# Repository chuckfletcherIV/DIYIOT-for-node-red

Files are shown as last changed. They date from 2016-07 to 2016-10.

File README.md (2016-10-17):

# DIYIOT
Open source IOT hardware and software platform based on cheap commodity sensors, ESP8266-12e chips, the MQTT protocol and powered by IBM's Node-Red (pre-installed with most new raspberry Pi 3 installations).

The goal of the project is to put sensors (and actuators like servos or leds) on a local wifi network as inexpensively as possible, ideally for under $7 or 8 per device (including a power supply). 

Using Node-red, these devices can trigger or be triggered by any IOT activity you can think of. Node-red has dozens of supported IOT hooks to services and devices, like Hue or Lifx light bulbs, twitter integration or even the ability to send txt messages via twilio.

No coding is required for basic functionality. All data is sent to Node-red for processing and triggering. Node-red lets you do alot without coding as well, but if you need to code, you can do what you need to with simple javascript. 

DIYIOT is great for home automation projects, DIY escape rooms and halloween displays, and even interactive installations. For more permanent installations, sensors can be soldered directly into the board, vs using a header (which makes the sensor swappable). 

See DIY Board and Sensor Pin Map to figure out what board to use for which sensor (or actuator), also see notes for more advanced usage.

You can use www.PCBGOGO.com to get your own boards made for under $1 each. Gerber files are available for download from our site under "PCB". Keep an eye out for other sources for DIYIOT boards over the coming months. 

If you find a cheap commodity sensor that works great with an exisiting board - let us know so we can add it to the list.

If there is a problem with a sensor firmware code, or pin map, let us know or share a fix.

Future project goals:

Automatic Device Discovery with mDNS (bonjour)

SSL Level Security 

Smaller board size

Long term power and battery opimization

Even more cost reduction per device if we can find engineering and manufacturing partners to work with. 

Thanks, 

the DIYIOT team

Join the DIYIOT for Node Red mailing list at https://groups.google.com/forum/#!forum/diyiot-node-red

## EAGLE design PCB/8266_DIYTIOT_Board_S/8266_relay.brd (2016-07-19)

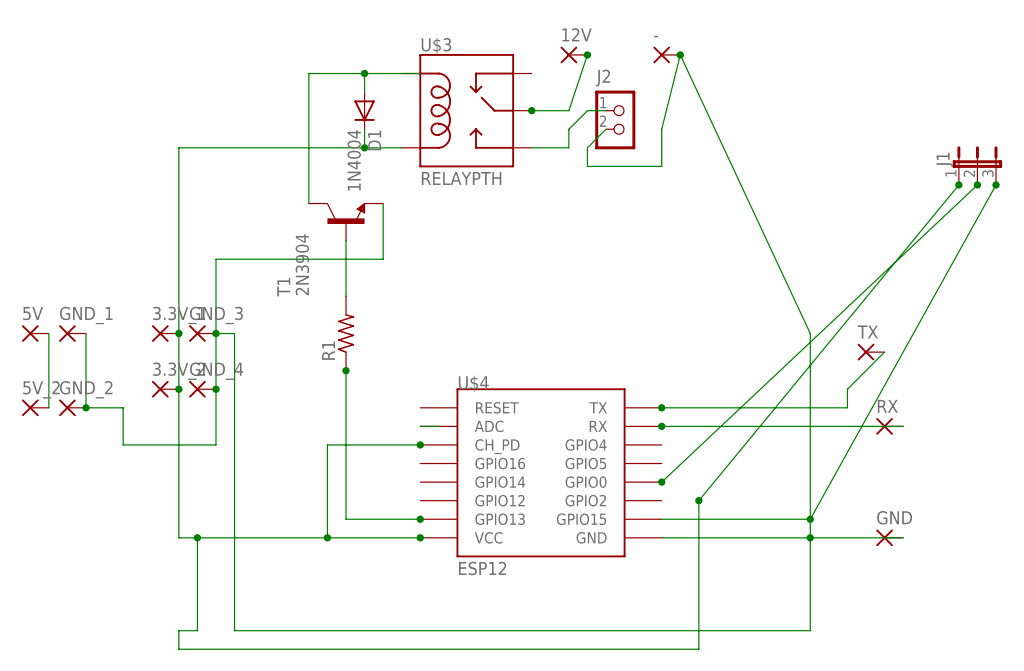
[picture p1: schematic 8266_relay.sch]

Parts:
3.3V_1, 3.3V_2, 5V, 5V_2, 12V: 2,15/1,0
-: 2,15/1,0
D1: 1N4004; DO41-10
GND: 2,15/1,0
GND_1, GND_2, GND_3, GND_4: 2,15/1,0
J1: JP2E; JP2
J2: CON_TERMINAL_BLOCK_02-5MM; TERMINAL_BLOCK_2P_5
R1: R-US_0309/10; 0309/10
RX: 2,15/1,0
T1: 2N3904; TO92
TX: 2,15/1,0
U$3: RELAYPTH; SRD-05VDC-SL-C
U$4: ESP12

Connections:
5V: 5V.1, 5V_2.1
12V: 12V.1, U$3.SWCOMMON
GND: -.1, GND.1, GND_1.1, GND_2.1, GND_3.1, GND_4.1, J1.3, J2.2, T1.3 (E), U$4.GND, U$4.GPIO15
unnamed: J1.2, U$4.GPIO0
unnamed: R1.1, U$4.GPIO13
unnamed: J2.1, U$3.SWOPEN
unnamed: 3.3V_1.1, 3.3V_2.1, D1.C, J1.1, U$3.COIL0, U$4.CH_PD, U$4.VCC
unnamed: D1.A, T1.1 (C), U$3.COIL1
unnamed: R1.2, T1.2 (B)
RX: RX.1, U$4.RX
TX: TX.1, U$4.TX

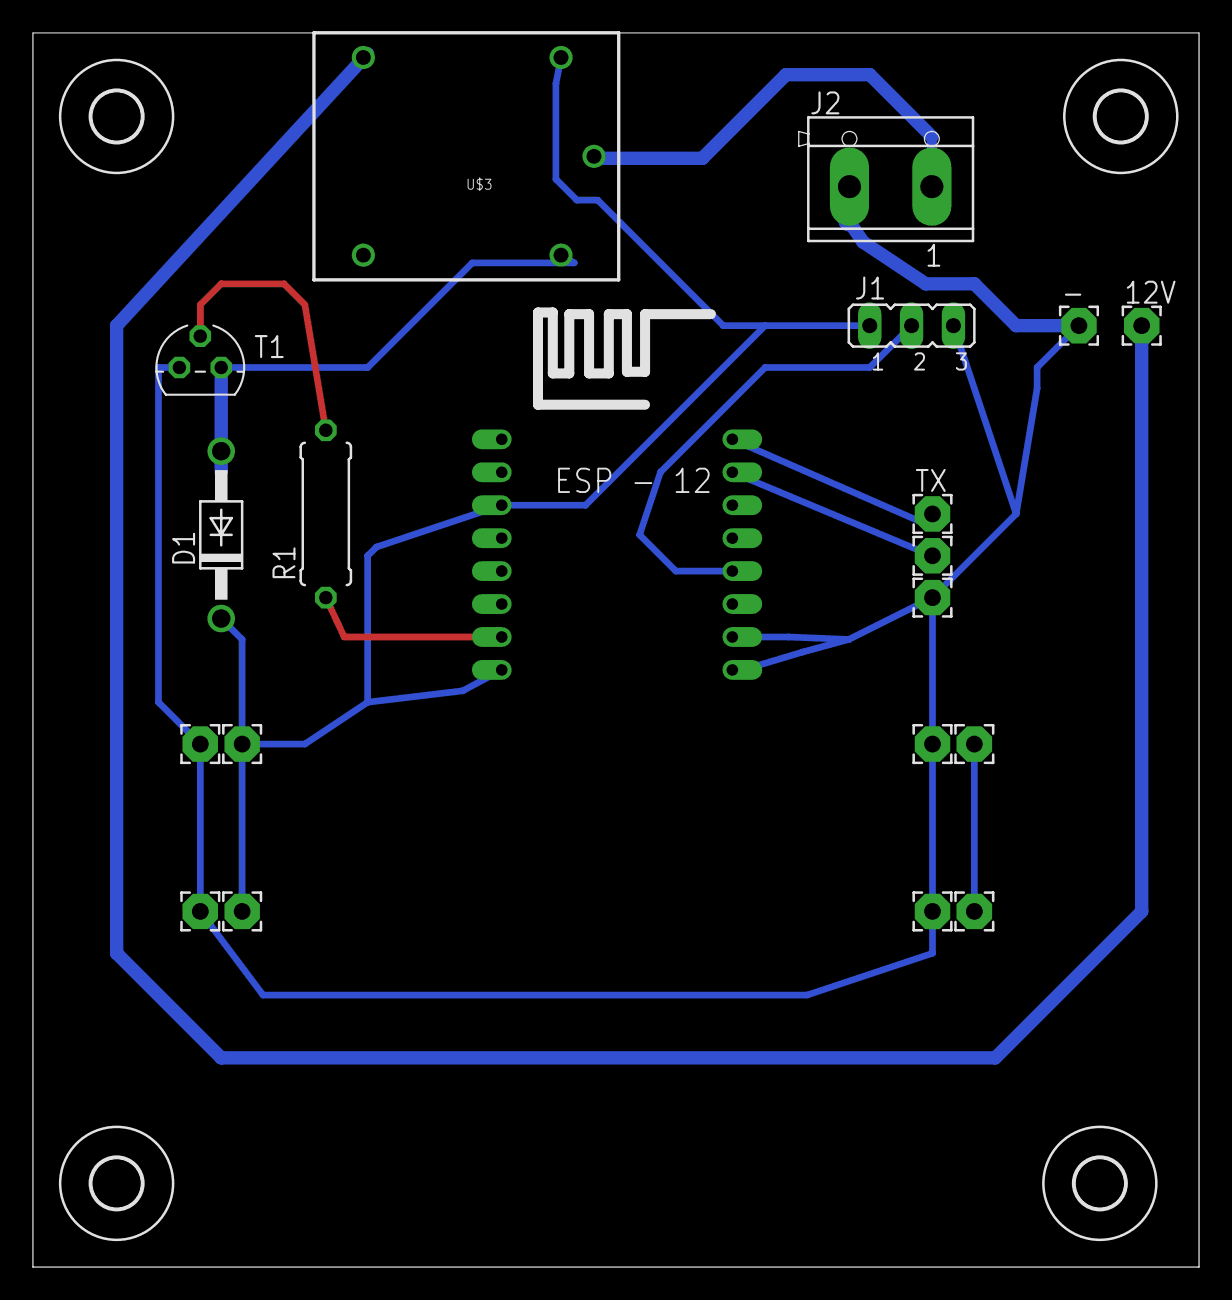
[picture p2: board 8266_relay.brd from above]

Board: 2 copper layers, 70.8 x 74.9 mm, 24 parts (0 on the bottom side), 11 nets.

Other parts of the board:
U$1, U$2, U$5, U$6: 3,0

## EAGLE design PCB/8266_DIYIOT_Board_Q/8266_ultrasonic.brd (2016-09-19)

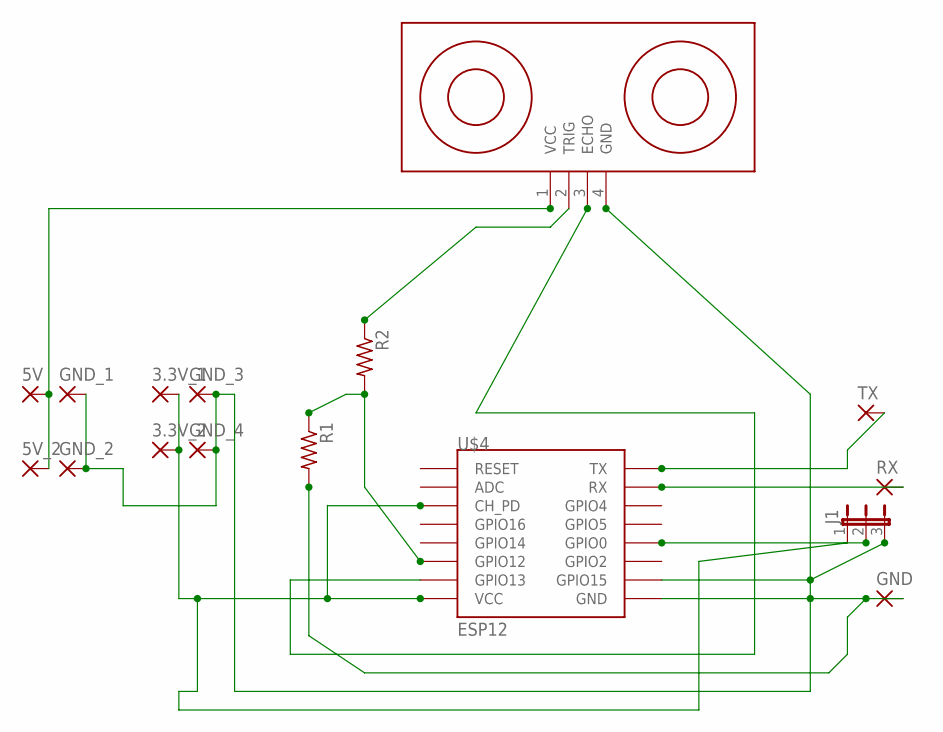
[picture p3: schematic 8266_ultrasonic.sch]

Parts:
3.3V_1, 3.3V_2, 5V, 5V_2: 2,15/1,0
GND: 2,15/1,0
GND_1, GND_2, GND_3, GND_4: 2,15/1,0
J1: JP2E; JP2
R1, R2: R-US_0207/10; 0207/10
RX: 2,15/1,0
TX: 2,15/1,0
U$3: ULTRASONIC-HC-SR04#V
U$4: ESP12

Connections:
5V: 5V.1, 5V_2.1, U$3.1 (VCC)
GND: GND.1, GND_1.1, GND_2.1, GND_3.1, GND_4.1, J1.3, R1.2, U$3.4 (GND), U$4.GND, U$4.GPIO15
unnamed: R2.1, U$3.2 (TRIG)
unnamed: J1.2, U$4.GPIO0
unnamed: R1.1, R2.2, U$4.GPIO12
unnamed: 3.3V_1.1, 3.3V_2.1, J1.1, U$4.CH_PD, U$4.VCC
unnamed: U$3.3 (ECHO), U$4.GPIO13
RX: RX.1, U$4.RX
TX: TX.1, U$4.TX

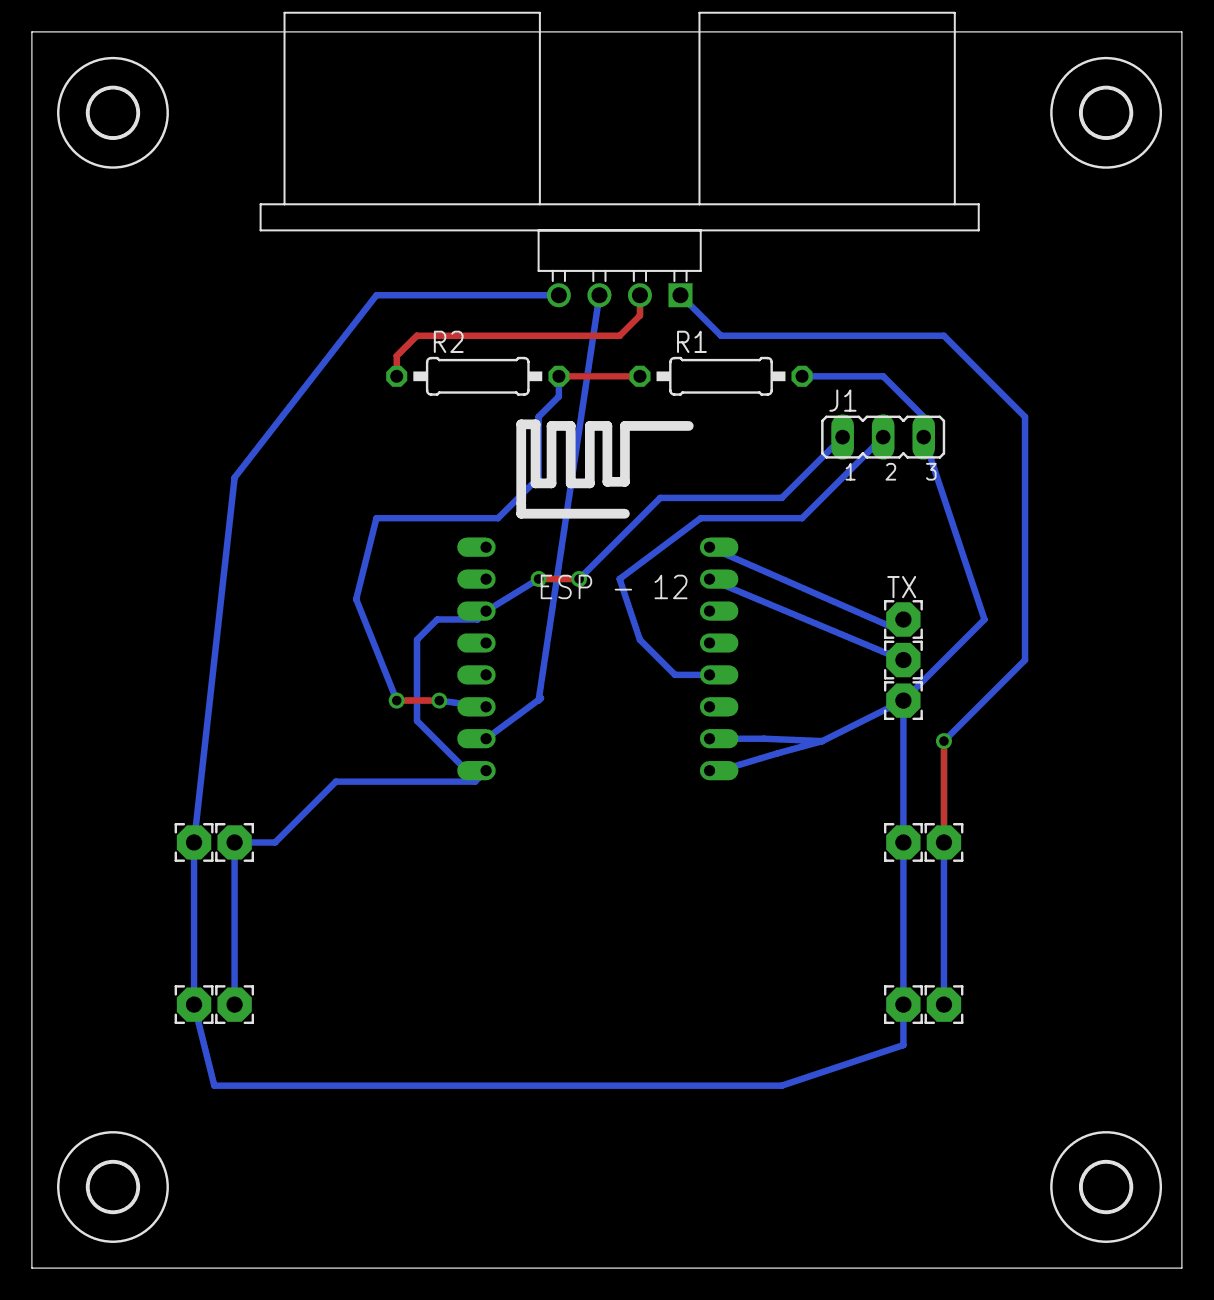
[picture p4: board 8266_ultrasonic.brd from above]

Board: 2 copper layers, 72.1 x 77.5 mm, 20 parts (0 on the bottom side), 9 nets.

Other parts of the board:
U$1, U$2, U$5, U$6: 3,0

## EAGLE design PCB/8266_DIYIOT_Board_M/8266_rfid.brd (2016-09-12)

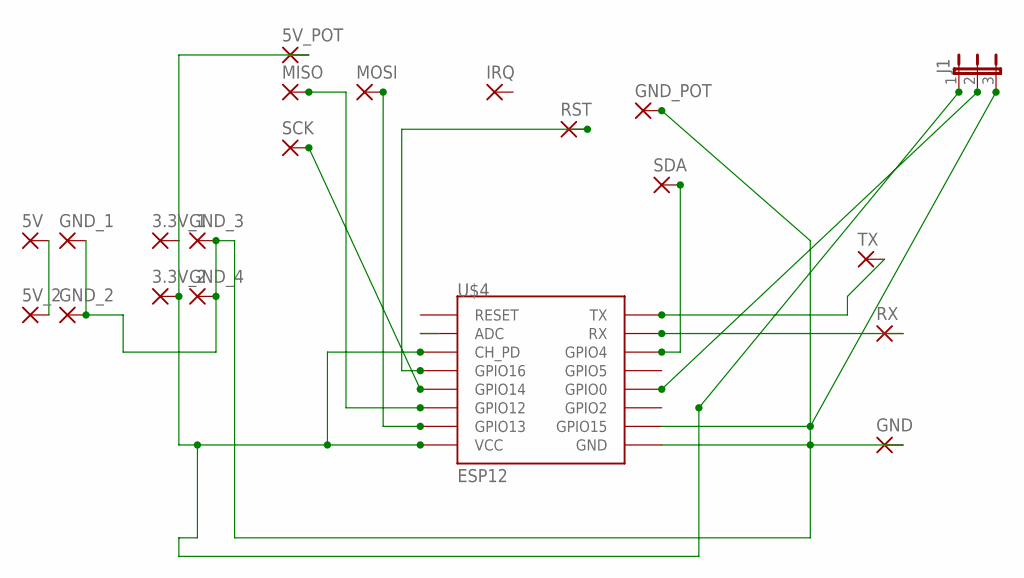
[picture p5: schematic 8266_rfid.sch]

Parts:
3.3V_1, 3.3V_2, 5V, 5V_2, 5V_POT: 2,15/1,0
GND: 2,15/1,0
GND_1, GND_2, GND_3, GND_4: 2,15/1,0
GND_POT: 2,15/1,0
IRQ: 2,15/1,0
J1: JP2E; JP2
MISO: 2,15/1,0
MOSI: 2,15/1,0
RST: 2,15/1,0
RX: 2,15/1,0
SCK: 2,15/1,0
SDA: 2,15/1,0
TX: 2,15/1,0
U$4: ESP12

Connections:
5V: 5V.1, 5V_2.1, GND.1, GND_1.1, GND_2.1, GND_3.1, GND_4.1, GND_POT.1, J1.3, U$4.GND, U$4.GPIO15
unnamed: J1.2, U$4.GPIO0
unnamed: SDA.1, U$4.GPIO4
unnamed: SCK.1, U$4.GPIO14
unnamed: 3.3V_1.1, 3.3V_2.1, 5V_POT.1, J1.1, U$4.CH_PD, U$4.VCC
unnamed: MOSI.1, U$4.GPIO13
unnamed: MISO.1, U$4.GPIO12
unnamed: RST.1, U$4.GPIO16
RX: RX.1, U$4.RX
TX: TX.1, U$4.TX

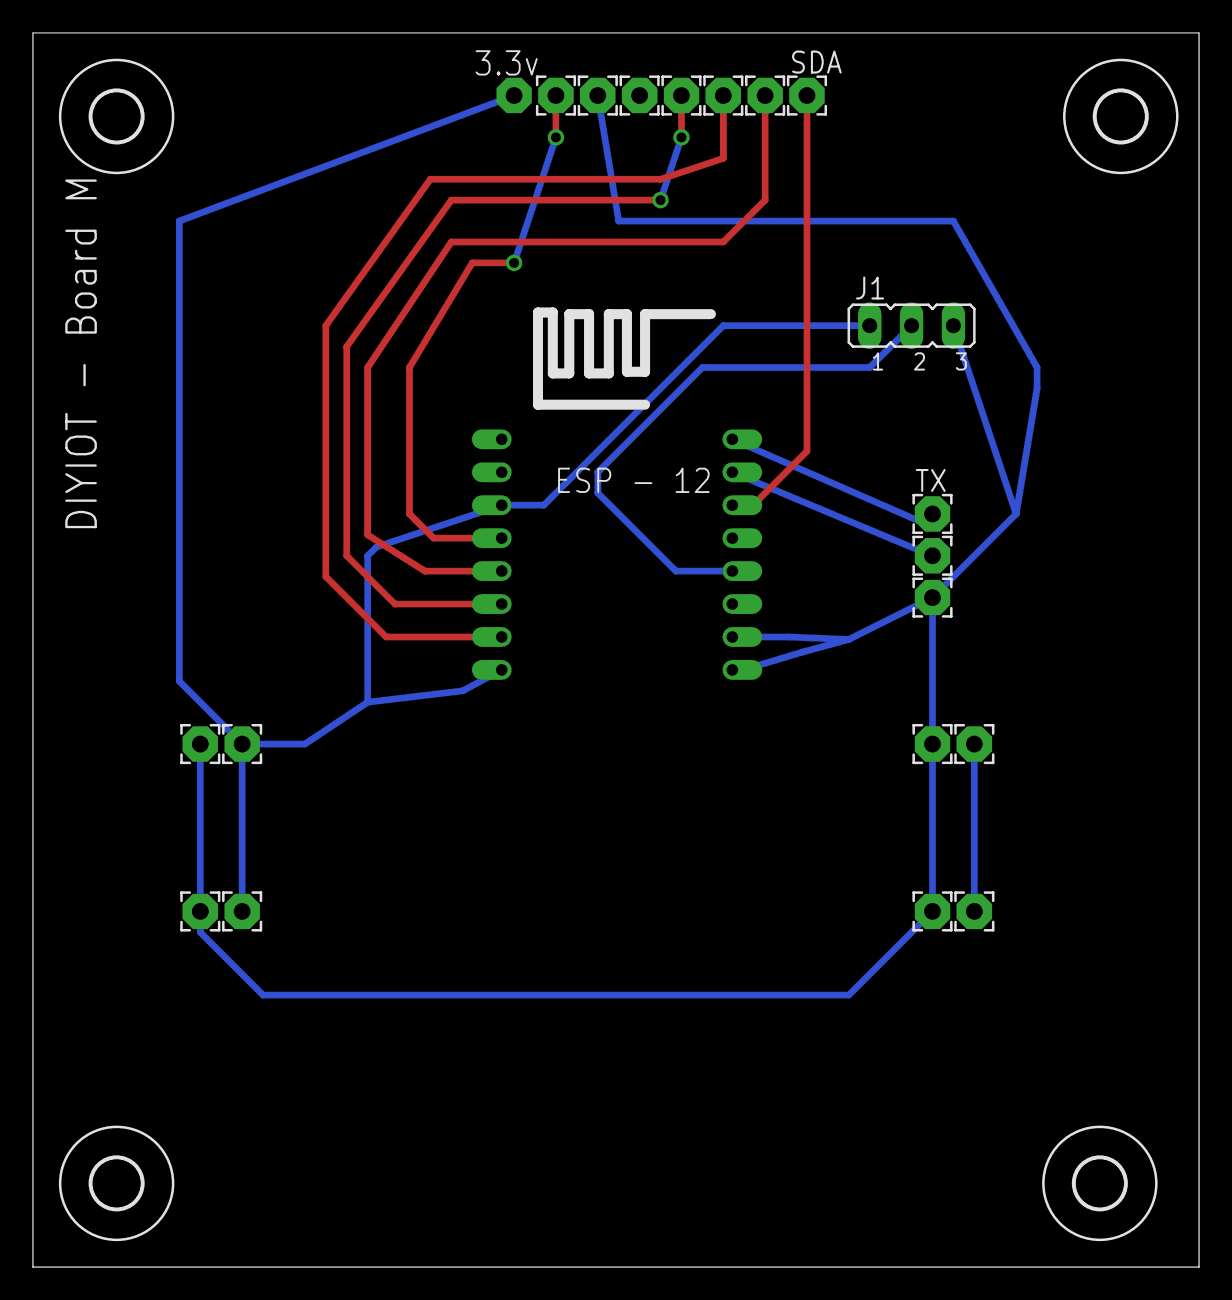
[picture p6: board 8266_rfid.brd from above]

Board: 2 copper layers, 70.8 x 74.9 mm, 25 parts (1 on the bottom side), 10 nets.

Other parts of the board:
U$1, U$2, U$5, U$6: 3,0

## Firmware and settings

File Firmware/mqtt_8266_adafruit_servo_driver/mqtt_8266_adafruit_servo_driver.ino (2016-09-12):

#include <ESP8266WiFi.h>
#include <PubSubClient.h>
#include <Servo.h> 
#include <Wire.h>
#include <Adafruit_PWMServoDriver.h>

Adafruit_PWMServoDriver pwm = Adafruit_PWMServoDriver();

#define SERVOMIN  104 // this is the 'minimum' pulse length count (out of 4096)
#define SERVOMAX  521 // this is the 'maximum' pulse length count (out of 4096)

int servonum = 0;

const char* ssid     = "DIYIOT";
const char* password = "diyiotdiyiot";
const char* mqtt_server = "10.10.10.3";
const char* topic = "servo/1";
char msg[50];
String myMsg;
String potValString;
String servonumString;
WiFiClient espClient;
PubSubClient client(espClient);

int potVal = 0; // Potentiometer value
int ledPosition; // Position of active LED
int lastpot = 0;  // last potentiometer reading to compare with

void setup()
{
  Serial.begin(115200);  
  setup_wifi();
  client.setServer(mqtt_server, 1883);
  client.setCallback(callback);
  pwm.begin();
  pwm.setPWMFreq(60);  // Analog servos run at ~60 Hz updates
}

void setup_wifi() {

  delay(10);
  // We start by connecting to a WiFi network
  Serial.println();
  Serial.print("Connecting to ");
  Serial.println(ssid);

  WiFi.begin(ssid, password);

  while (WiFi.status() != WL_CONNECTED) {
    delay(500);
    Serial.print(".");
  }

  Serial.println("");
  Serial.println("WiFi connected");
  Serial.println("IP address: ");
  Serial.println(WiFi.localIP());
}

void callback(char* topic, byte* payload, unsigned int length) {
//  Serial.print("Message arrived [");
//  Serial.print(topic);
//  Serial.print("] ");
  payload[length] = '\0';
  String message = String((char*)payload);
  int commaIndex = message.indexOf(',');
  int secondCommaIndex = message.indexOf(',', commaIndex+1);
  servonumString = message.substring(0, commaIndex);
  
//  Serial.print("Servo Num is ");
//  Serial.println(servonumString);
  potValString = message.substring(commaIndex+1, secondCommaIndex);
  potVal = potValString.toInt();
}

void reconnect() {
  // Loop until we're reconnected
  while (!client.connected()) {
    
    //Serial.print("Attempting MQTT connection...");
    if (client.connect(topic)) {
        Serial.println("connected");
      // Once connected, publish an announcement...
      client.publish("channels", "servo/1");
      client.publish(topic, "connected");
      // ... and resubscribe
      client.subscribe(topic);
    } else {
     // Serial.print("failed, rc=");
     // Serial.print(client.state());
     // Serial.println(" try again in 5 seconds");
      // Wait 5 seconds before retrying
      delay(500);
    }
  }
}

void loop()
{ 
    if (!client.connected()) {
    reconnect();
    }

    client.loop(); 
        
        servonum = (uint8_t) servonumString.toInt();
        uint16_t pulselen = map(potVal, 0, 360, SERVOMIN, SERVOMAX);
        pwm.setPWM(servonum, 0, pulselen);
//        Serial.print("potval: " + String(potVal) + ": ");
//        Serial.print("pulselength: " + String(pulselen));
//        Serial.println(": " + servonumString);
}

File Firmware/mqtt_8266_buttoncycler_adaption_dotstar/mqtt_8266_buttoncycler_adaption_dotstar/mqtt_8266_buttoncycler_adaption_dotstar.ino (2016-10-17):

#include <SPI.h>
#include <ESP8266WiFi.h>
#include <PubSubClient.h>
#ifdef __AVR__
  #include <avr/power.h>
#endif

const char* ssid     = "DIYIOT";
const char* password = "diyiotdiyiot";
const char* mqtt_server = "10.10.10.3";
const char* topic = "neopixel_ring/1";
char msg[50];
char message_buffer[100];
String myMsg;
int redValue = 255;
int greenValue = 255;
int blueValue = 255;
int delayval = 500; // delay for half a second

WiFiClient espClient;
PubSubClient client(espClient);

#include <Adafruit_DotStar.h>
// Because conditional #includes don't work w/Arduino sketches...
#include <SPI.h>    


#define NUMPIXELS 250 // Number of LEDs in strip

// Here's how to control the LEDs from any two pins:
#define DATAPIN    4
#define CLOCKPIN   5
Adafruit_DotStar strip = Adafruit_DotStar(NUMPIXELS, DATAPIN, CLOCKPIN, DOTSTAR_BRG);

bool oldState = true;
int showType = 0;

void setup() {
  Serial.begin(115200);  
  setup_wifi();
  client.setServer(mqtt_server, 1883);
  client.setCallback(callback);
  strip.begin();  // Call this to start up the LED strip.
  strip.setBrightness(20);
  rainbowCycle(20);
}


void setup_wifi() {

  delay(10);
  // We start by connecting to a WiFi network
  Serial.println();
  Serial.print("Connecting to ");
  Serial.println(ssid);

  WiFi.begin(ssid, password);

  while (WiFi.status() != WL_CONNECTED) {
    delay(500);
    Serial.print(".");
  }

  Serial.println("");
  Serial.println("WiFi connected");
  Serial.println("IP address: ");
  Serial.println(WiFi.localIP());
}

void callback(char* topic, byte* payload, unsigned int length) {
 int i = 0;
  Serial.print("Message arrived [");
  Serial.print(topic);
  Serial.println("] ");
  payload[length] = '\0';
  String myTopic = String((char*)topic);
  Serial.println("Received: " + String(myTopic));
  
if ( myTopic == "neopixel_ring/1") {
    String message = String((char*)payload);
    Serial.println("Received: " + String(message));
    redValue = getValue(message, ',', 0).toInt();
    greenValue = getValue(message, ',', 1).toInt();
    blueValue = getValue(message, ',', 2).toInt();
    Serial.println("Red: " + String(redValue) + " Green: " + String(greenValue) + " Blue: " + String(blueValue));
    colorWipe(strip.Color(redValue, greenValue, blueValue), 50);
}
     
 if (myTopic == "neopixel_ring/1/brightness") {
    String brightness = String((char*)payload);
    int myBrightness = brightness.toInt();
    Serial.println("Received: " + String(brightness));
    strip.setBrightness(myBrightness);
    strip.show();
  }
  
   if (myTopic == "neopixel_ring/1/reset") {
    strip.setBrightness(20);
    rainbowCycle(20);
  }
}

void reconnect() {
  // Loop until we're reconnected
  while (!client.connected()) {
    
      Serial.print("Attempting MQTT connection...");
    // Attempt to connect
    if (client.connect(topic)) {
      Serial.println("connected");
      // Once connected, publish an announcement...
      client.publish(topic, "connected");
      // ... and resubscribe
      client.subscribe(topic);
      client.subscribe("neopixel_ring/1/brightness");
      client.subscribe("neopixel_ring/1/reset");
    } else {
      Serial.print("failed, rc=");
      Serial.print(client.state());
      Serial.println(" try again in 5 seconds");
      // Wait 5 seconds before retrying
      delay(3000);
    }
  }
}

void loop() {
//  colorWipe(strip.Color(0, 255, 0), 50); // Green
//  colorWipe(strip.Color(0, 0, 255), 50); // Blue
//  theaterChase(strip.Color(127, 127, 127), 50); // White
//  theaterChase(strip.Color(127, 0, 0), 50); // Red
//  theaterChase(strip.Color(0, 0, 127), 50); // Blue
//  rainbow(20);
//  rainbowCycle(20);
//  theaterChaseRainbow(50);
  
    if (!client.connected()) {
    reconnect();
    yield();
  }
    client.loop();

  }
  

String getValue(String data, char separator, int index)
{
 int found = 0;
  int strIndex[] = {
0, -1  };
  int maxIndex = data.length()-1;
  for(int i=0; i<=maxIndex && found<=index; i++){
  if(data.charAt(i)==separator || i==maxIndex){
  found++;
  strIndex[0] = strIndex[1]+1;
  strIndex[1] = (i == maxIndex) ? i+1 : i;
  }
 }
  return found>index ? data.substring(strIndex[0], strIndex[1]) : "";
}

// Fill the dots one after the other with a color
void colorWipe(uint32_t c, uint8_t wait) {
  for(uint16_t i=0; i<strip.numPixels(); i++) {
    strip.setPixelColor(i, c);
    strip.show();
    delay(wait);
    yield();
  }
}

void rainbow(uint8_t wait) {
  uint16_t i, j;

  for(j=0; j<256; j++) {
    for(i=0; i<strip.numPixels(); i++) {
      strip.setPixelColor(i, Wheel((i+j) & 255));
    }
    strip.show();
    delay(wait);
  }
}

// Slightly different, this makes the rainbow equally distributed throughout
void rainbowCycle(uint8_t wait) {
  uint16_t i, j;

  for(j=0; j<256*5; j++) { // 5 cycles of all colors on wheel
    for(i=0; i< strip.numPixels(); i++) {
      strip.setPixelColor(i, Wheel(((i * 256 / strip.numPixels()) + j) & 255));
    }
    strip.show();
    delay(wait);
    yield();
  }
}

//Theatre-style crawling lights.
void theaterChase(uint32_t c, uint8_t wait) {
  for (int j=0; j<10; j++) {  //do 10 cycles of chasing
    for (int q=0; q < 3; q++) {
      for (uint16_t i=0; i < strip.numPixels(); i=i+3) {
        strip.setPixelColor(i+q, c);    //turn every third pixel on
      }
      strip.show();

      delay(wait);

      for (uint16_t i=0; i < strip.numPixels(); i=i+3) {
        strip.setPixelColor(i+q, 0);        //turn every third pixel off
      }
    }
  }
}

//Theatre-style crawling lights with rainbow effect
void theaterChaseRainbow(uint8_t wait) {
  for (int j=0; j < 256; j++) {     // cycle all 256 colors in the wheel
    for (int q=0; q < 3; q++) {
      for (uint16_t i=0; i < strip.numPixels(); i=i+3) {
        strip.setPixelColor(i+q, Wheel( (i+j) % 255));    //turn every third pixel on
      }
      strip.show();

      delay(wait);

      for (uint16_t i=0; i < strip.numPixels(); i=i+3) {
        strip.setPixelColor(i+q, 0);        //turn every third pixel off
      }
    }
  }
}

// Input a value 0 to 255 to get a color value.
// The colours are a transition r - g - b - back to r.
uint32_t Wheel(byte WheelPos) {
  WheelPos = 255 - WheelPos;
  if(WheelPos < 85) {
    return strip.Color(255 - WheelPos * 3, 0, WheelPos * 3);
  }
  if(WheelPos < 170) {
    WheelPos -= 85;
    return strip.Color(0, WheelPos * 3, 255 - WheelPos * 3);
  }
  WheelPos -= 170;
  return strip.Color(WheelPos * 3, 255 - WheelPos * 3, 0);
}

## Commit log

2016-09-12 lots of updates. Renamed and organized boards
    [8266_3_pin_digital.brd, 8266_3_pin_digital_center_pin.brd, 8266_DIYIOT_Board_B_DS_V_G.brd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]
2016-09-19 lots of updates
    [8266_DIYIOT_Board_C_G_V_AS.brd, 8266_DIYIOT_Board_C_G_V_AS.sch, 8266_DIYIOT_Board_F_AS_V_G.brd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]
2016-09-19 cleaned up folders
    [8266_relay.brd, 8266_relay.sch]
2016-09-19 added pin map files
    [DIYIOT - Board and Sensor Pin Map.csv, DIYIOT - Board and Sensor Pin Map.xls, DIYIOT - Board and Sensor Pin Map.xlsx]
2016-09-19 cleaned up pin map files
    [DIYIOT - Board and Sensor Pin Map.csv, DIYIOT - Board and Sensor Pin Map.xls, DIYIOT - Board and Sensor Pin Map.xlsx]
2016-09-19 updated firmware status
    [DIYIOT - Board and Sensor Pin Map.xlsx]
2016-10-17 updated stuff
    [DIYIOT - Board and Sensor Pin Map.xlsx]

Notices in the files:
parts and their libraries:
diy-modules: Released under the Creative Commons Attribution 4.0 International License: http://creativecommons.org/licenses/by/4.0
